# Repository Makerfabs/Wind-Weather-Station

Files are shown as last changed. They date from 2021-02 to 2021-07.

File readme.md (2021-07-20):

# Wind Weather Station

```c++
/*
Version:		V2.0
Author:			Vincent
Create Date:	2021/2/23
Note:
	2021/7/20: Add a weather station project.
	2021/5/5:Add Seeed UV Sensor example.
	
*/
```
[toc]

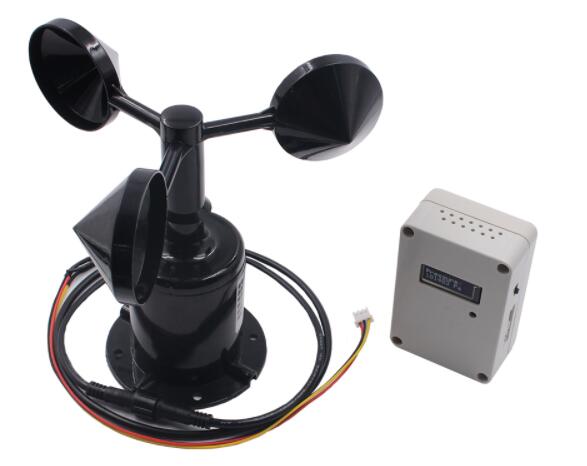
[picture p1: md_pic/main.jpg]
main


[DIY Wind Weather Station and Remote Monitor via MQTT](https://www.youtube.com/watch?v=OUKzvni5h78)

# Makerfabs

[Makerfabs home page](https://www.makerfabs.com/)

[Makerfabs Wiki](https://makerfabs.com/wiki/index.php?title=Main_Page)

# Wind Weather Station

## Intruduce

### Product Link: [Open Wind Station GPRS/ MQTT](https://www.makerfabs.com/open-wind-statation-gprs-mqtt.html)

### Wiki Link:[Wind_Weather_Station](https://www.makerfabs.com/wiki/index.php?title=Wind_Weather_Station)

Weather station based on Maduino A9G.With onboard DHT11 temperature and humidity sensor, BMP280 air pressure sensor and SSD1306LCD screen.It can be connected with anemometer and PM2.5 air quality sensor.

## Feature

- Micro controller ATSAMD21G18, 32-Bit ARM Cortex M0+
- PM2.5 monitoring with expanded PM2.5 sensor
- GPS for locating
- Grove connectors for customers’ expanded testing
- OLED display for real-time checking& debugging
- Onboard buzzer/ SD card slot
- High-power 1000 mAH battery for long-term usage
- Solar panel charging
- With Case(but not water-proof), could be re-made for water-proof with glues easily
- Arduino compatible/ Support MQTT

### Front:

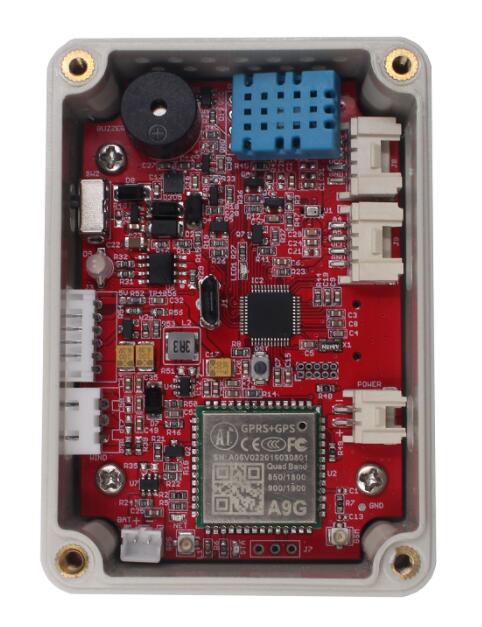
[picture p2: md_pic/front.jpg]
front


### Back:
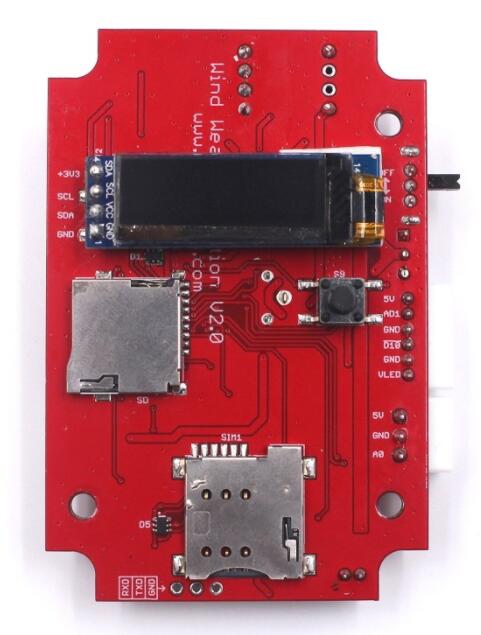
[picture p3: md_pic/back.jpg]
back


### Interface:

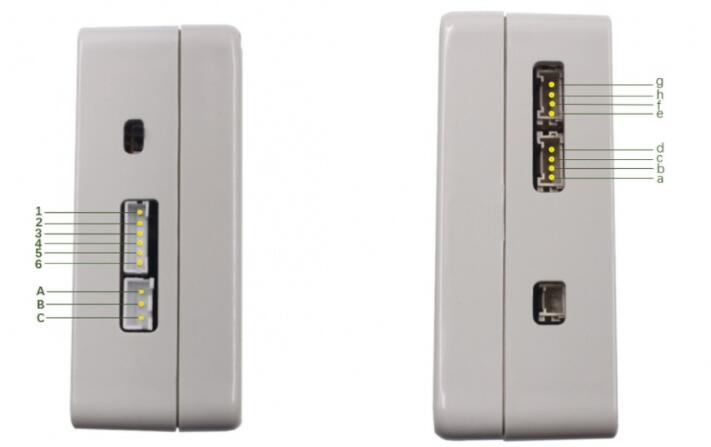
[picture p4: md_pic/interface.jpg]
interface


1. Interface of anemometer

| Pin | Mark | Definition |
| ---- | ---- | ---- |
| A | VCC | Power supply |
| B | GND | Grounding |
| C | A0 | Data input  |

2. Interface of CO2 sensor

| Pin| 	Mark	|Definition |
| ---- | ---- | ---- |
| 1 | 5V | Power supply |
| 2 | AD1 |  Data input |
| 3 | GND |  Grounding |
| 4 | D10 |  LED Driving |
| 5 | GND |  LED grounding |
| 6 | VLED | LED Power supply |

3. Other interfaces

| Pin| 	Mark	|Definition |
| ---- | ---- | ---- |
| a | | GND |
| b | | VCC |
| c | | A5 |
| d | | A4 |
| e | | GND |
| f | | VCC |
| g | | SDA |
| h | | SCL |

# Example

## Compiler Options

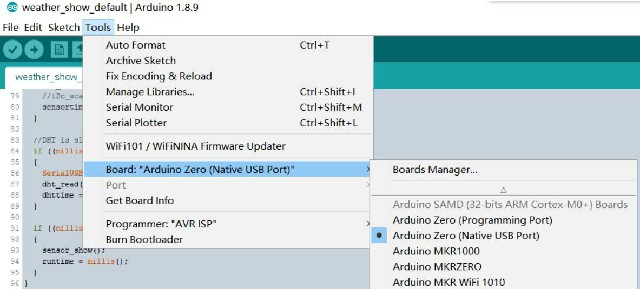
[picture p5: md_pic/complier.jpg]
complier


Choice Arduino Zero (Native USB Port).

## weather_show_default

Factory default program, collect temperature, humidity, air pressure, wind speed, PM2.5 index, the sensor data display on SSD1306.

- Connect anemometer or air quality sensor (or both) to weather station.
- Connect to battery or USB cable.
- LCD screen will show sensor value.

## at_demo

A simple AT directive demo is provided.

## weather_MQTT

A simple example of MQTT communication. Data is sent by MQTT protocol through A9G module. Need a SIM card that can be connected to the Internet.

## low_power

A simple low-power test program that turns off power to the A9G and all sensors and puts the SAMD21 to sleep.

# Project : Weather Station

**A long-maintained weather station project, real-time weather from Makerfabs can be accessed via ThingSpeak and Makerfabs Wiki (Shenzhen, China).**

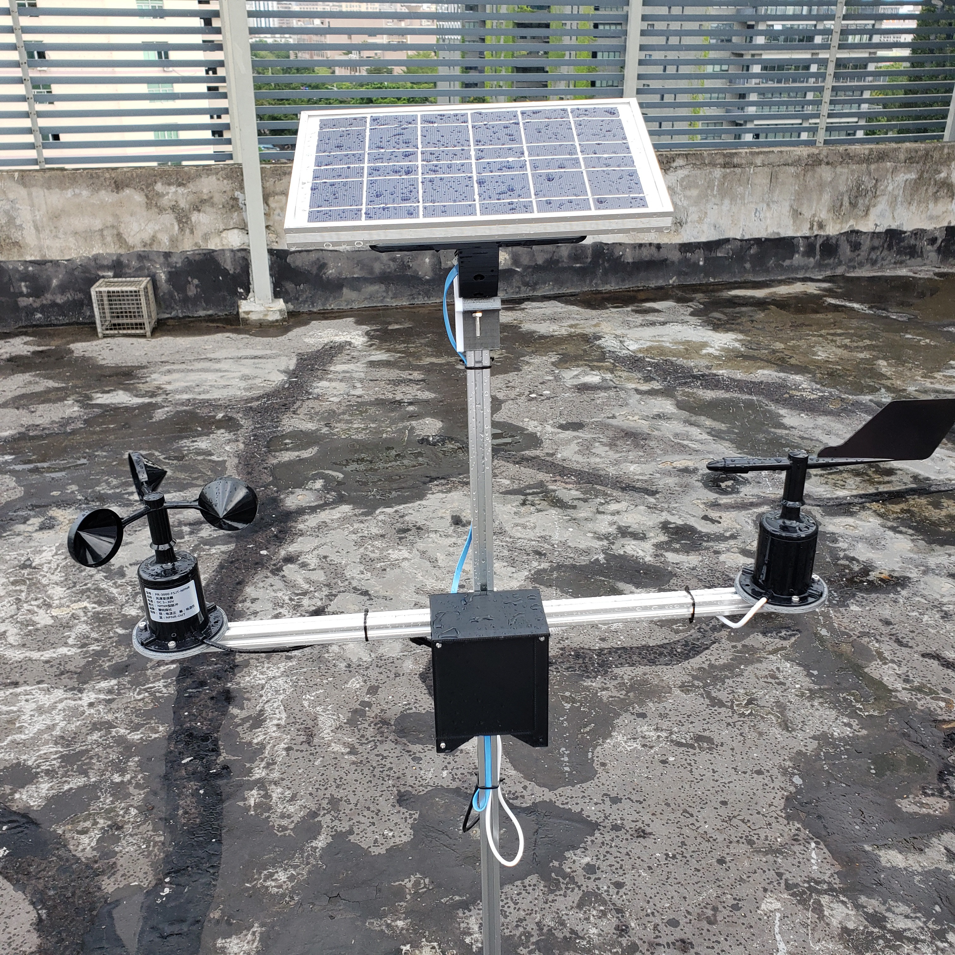
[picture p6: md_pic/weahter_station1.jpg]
weather_station


The weather link is as follows:

[Makerfabs Wiki Weather](https://www.makerfabs.com/wiki/index.php?title=Weather_Show)

[ThingSpeak Show](https://thingspeak.com/channels/1243124)

[HackDay.io wind weather station](https://hackaday.io/project/177972-wind-weather-station)

## Code

The code is divided into two parts, one is the Weather Station, which measures the weather data and sends it to ThingSpeak and MQTT servers.

And there is a use of ESP32 as a terminal to receive real-time information code.

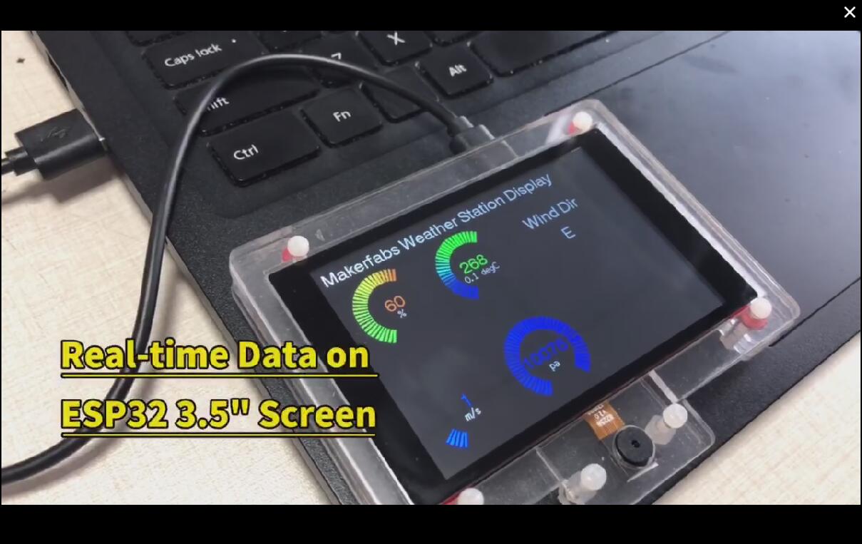
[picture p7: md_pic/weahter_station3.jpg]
weather_station3


## Weather Analysis

The test lasted for ten days in June, and the analysis data are as follows.

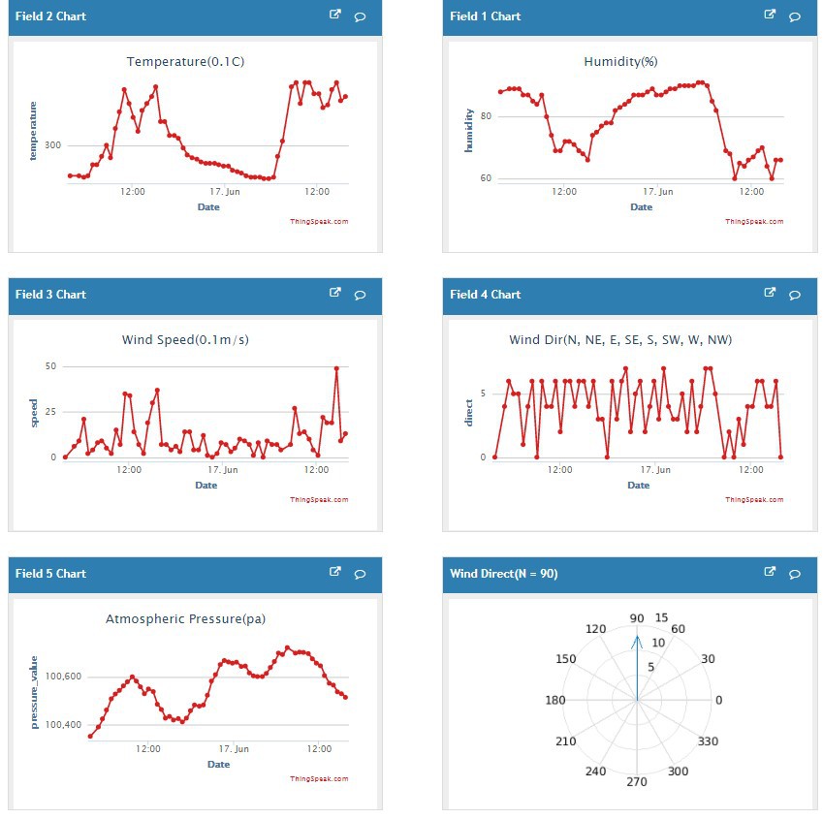
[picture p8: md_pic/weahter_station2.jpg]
weather_station


And I also make a python file to analyse data, like max or min temperature.

Code is in : \Wind-Weather-Station\Project_WeatherStation\csv_read\csv_test.py

## 3D file

Weather station box and anemometer, wind direction gauge, fixed structure of solar panel.

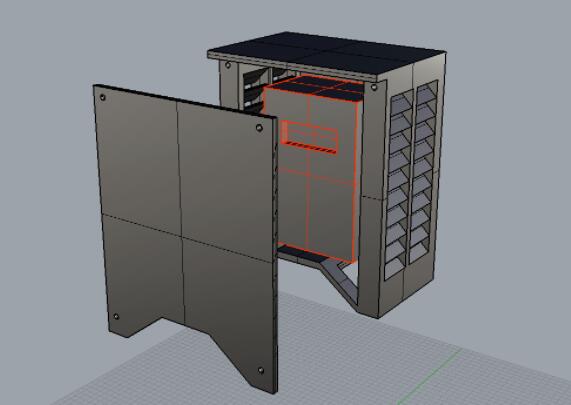
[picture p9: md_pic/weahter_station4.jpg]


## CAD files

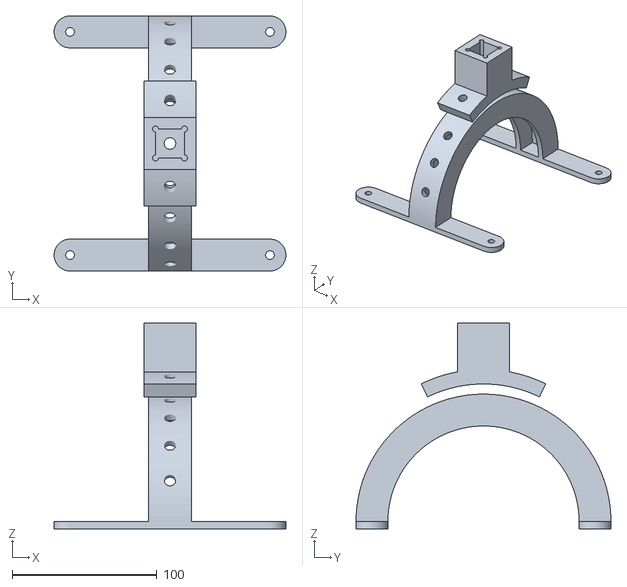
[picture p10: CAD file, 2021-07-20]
STL/weathersation_2.stl.stl
160.0 x 176.0 x 142.0

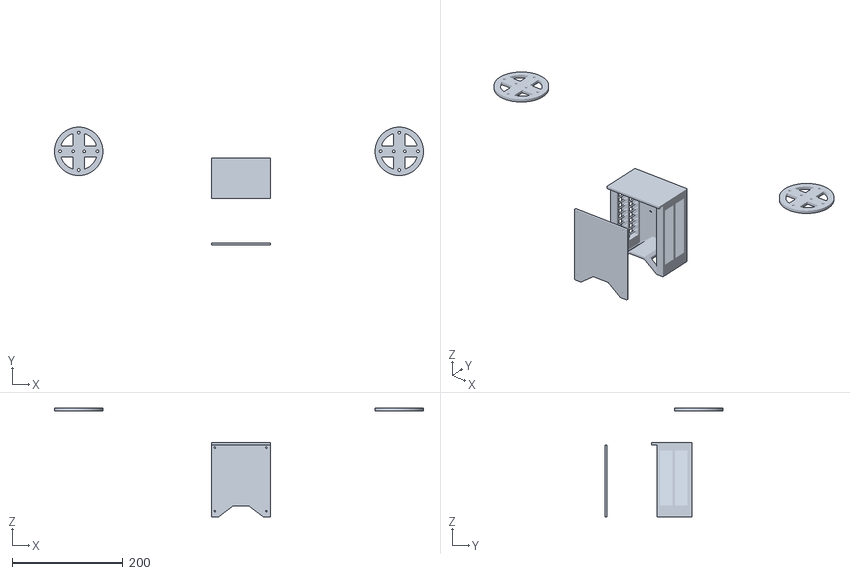
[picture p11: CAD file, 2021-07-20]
STL/weathersation_1.stl
666.5 x 212.8 x 196.0

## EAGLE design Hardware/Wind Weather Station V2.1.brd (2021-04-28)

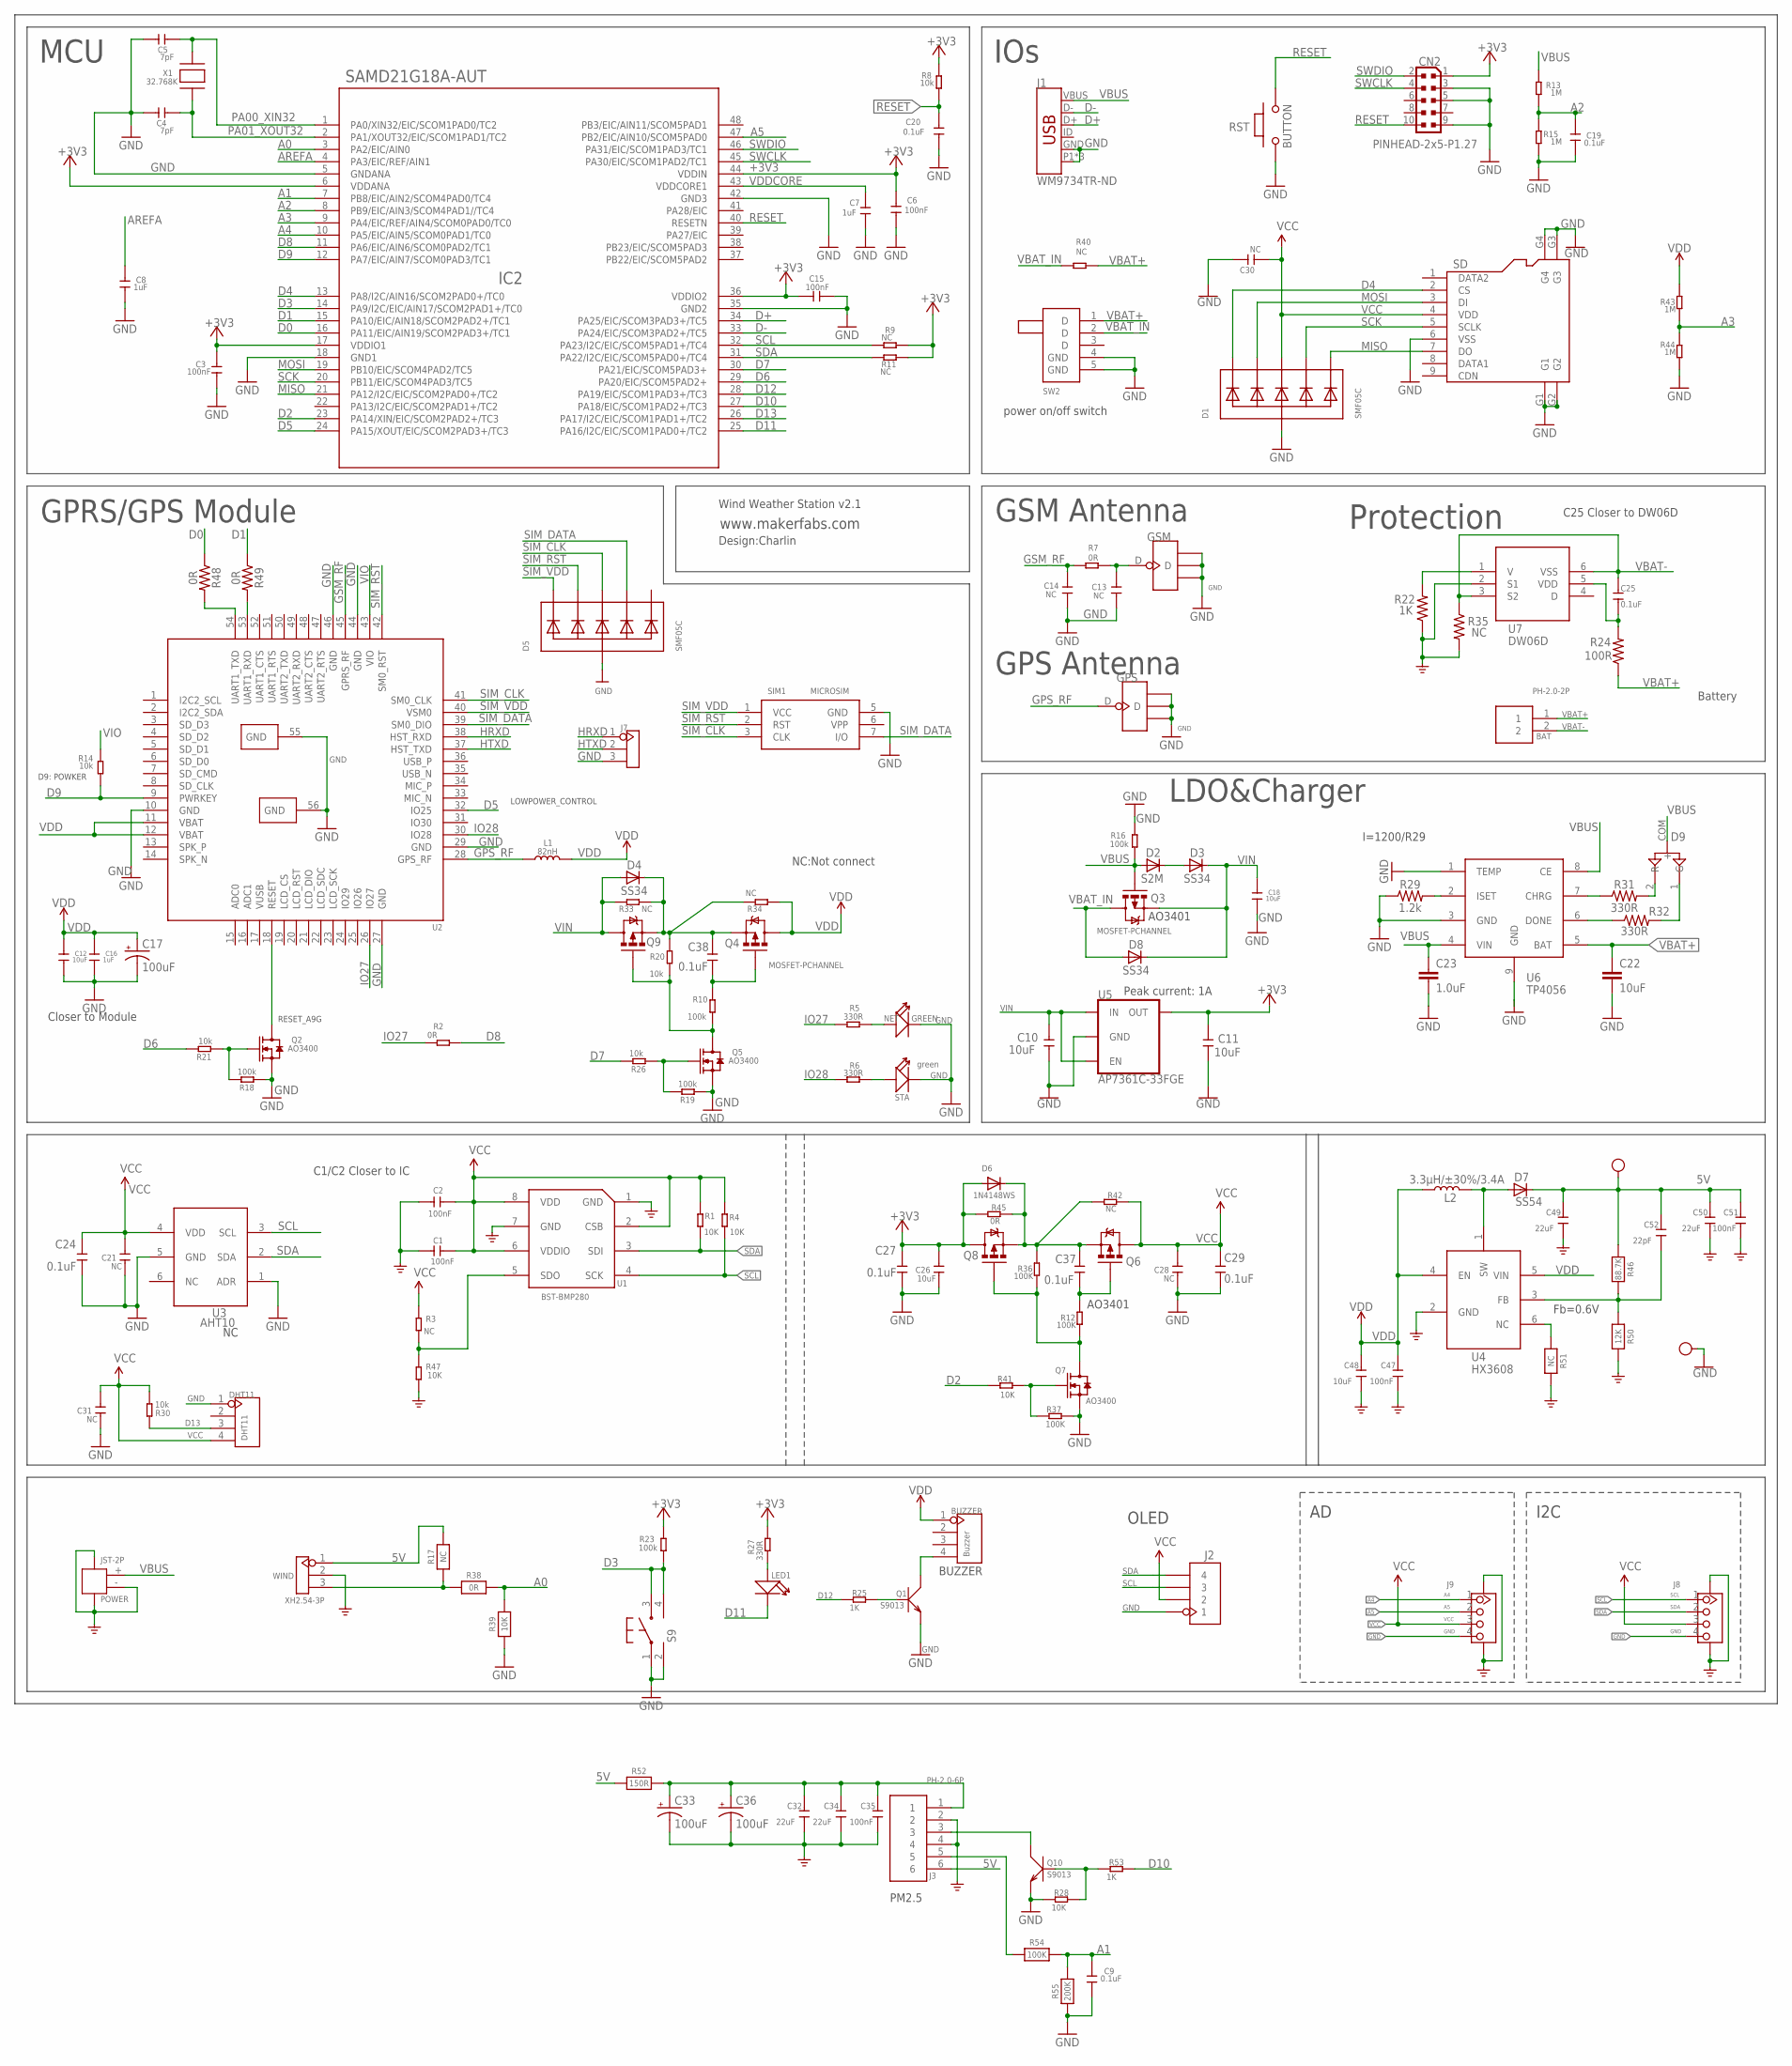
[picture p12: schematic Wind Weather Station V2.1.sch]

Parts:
5V: TEST-POINT'4545'; TP-D45MIL
BAT: PH-2.0-2P
BUZZER: Buzzer; 4P-65/35ROUND
C1, C2, C35, C47, C51: 100nF; C0603
C3, C6, C15: 100nF; 0603
C4, C5: 7pF; 0603
C7, C8, C16: 1uF; 0603
C9, C19, C20, C24, C25, C27, C29, C37, C38: 0.1uF; 0603
C10, C11, C12, C18, C26: 10uF; 0603
C13, C14: NC; 0402
C17, C33, C36: 100uF; EIA3528
C21, C28, C31: NC; 0603
C22: 10uF; 1206
C23: 1.0uF; 0603
C30: NC; DISCRETE_C0603
C32, C34, C49, C50: 22uF; C0603
C48: 10uF; C0603
C52: 22pF; C0603
CN2: PINHEAD-2x5-P1.27; PINHEAD_2X05_127
D1, D5: SMF05C; SOT363
D2: S2M; DO-214AC
D3, D4, D8: SS34; DO-214AC
D6: 1N4148WS; SOD-323F
D7: SS54; DO-214AC
D9: LED-ARG-3P'-3MM'; LED-3P-2.54-3MM
DHT11: DHT11; 4P-65/35ROUND
GND: TEST-POINT'4545'; TP-D45MIL
GPS: ANTENNA-U-FL; 4P-U-FL
GSM: ANTENNA-U-FL; 4P-U-FL
IC2: SAMD21G18A-AUT; TQFP48-7X7
J1: WM9734TR-ND; USB-B-MICRO-SMD_VERT
J2: HEADER-1X4P; SMD4-2.54P
J3: PH-2.0-6P
J7: HEADER-3P-2.54; 3P-2.54
J8, J9: GROVE-CONNECTOR-SMD'90D'; HW4-SMD-2.0-90D
L1: 82nH; L0603
L2: 3.3µH/±30%/3.4A; CR54
LED1: DISCRETE_LED0603; DISCRETE_LED-0603
NET: GREEN; DISCRETE_LED-0603
POWER: JST-2P; HW2-SMD-2.0-90D
Q1, Q10: S9013; SOT23
Q2, Q5: AO3400; SOT23@1
Q3, Q4, Q6, Q8, Q9: MOSFET-PCHANNEL; SOT23-3
Q7: AO3400; DISCRETE_SOT23
R1, R4, R28, R41, R47: 10K; R0603
R2, R7, R45: 0R; R0603
R3, R9, R11, R33, R34, R40, R42: NC; R0603
R5, R6, R27: 330R; R0603
R8, R14, R20, R21, R26, R30: 10k; R0603
R10, R16, R18, R19, R23: 100k; R0603
R12, R36, R37: 100K; R0603
R13, R15, R43, R44: 1M; R0603
R17, R51: NC; 0603-NO
R22: 1K; 0603
R24: 100R; 0603
R25, R53: 1K; R0603
R29: 1.2k; 0603
R31, R32: 330R; 0603
R35: NC; 0603
R38: 0R; 0603-NO
R39: 10K; 0603-NO
R46: 88.7K; 0603-NO
R48, R49: 0R; 0603
R50: 12K; 0603-NO
R52: 150R; 0603-NO
R54: 100K; 0603-NO
R55: 200K; 0603-NO
RST: BUTTON; 157SW
S9: SWITCHES; SMD4-6*6
SD: HOLDER-MICROSD-9P; 9P-SMD-W/-RING
SIM1: MICROSIM
STA: green; LED-0603
SW2: SWITCH; DIP5-8.6*4.5MM
U1: BST-BMP280; LGA8-0.65-2X2.5X0.95MM
U2: A9G
U3: AHT10; SMD6-127P-400L500W
U4: HX3608; SOT-23-6
U5: AP7361C-33FGE; 8-UDFN
U6: TP4056; SOP8-1.27P
U7: DW06D; SOT-23-6
WIND: XH2.54-3P
X1: 32.768K; XTAL3215

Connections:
5V: 5V.T, C49.1, C50.1, C51.1, C52.1, D7.C, J3.6, R17.2, R46.1, R52.1, WIND.1
+3V3: C3.2, C6.1, C11.2, C15.1, C26.2, C27.2, CN2.1, D6.A, IC2.6 (VDDANA), IC2.17 (VDDIO1), IC2.36 (VDDIO2), IC2.44 (VDDIN), Q8.3 (D), R8.2, R9.2, R11.2, R23.2, R27.2, R45.2, U5.1 (OUT)
A0: IC2.3 (PA2/EIC/AIN0), R38.2, R39.2
A1: C9.1, IC2.7 (PB8/EIC/AIN2/SCOM4PAD0/TC4), R54.2, R55.2
A2: C19.1, IC2.8 (PB9/EIC/AIN3/SCOM4PAD1//TC4), R13.1, R15.2
A3: IC2.9 (PA4/EIC/REF/AIN4/SCOM0PAD0/TC0), R43.1, R44.2
A4: IC2.10 (PA5/EIC/AIN5/SCOM0PAD1/TC0), J9.1
A5: IC2.47 (PB2/EIC/AIN10/SCOM5PAD0), J9.2
AREFA: C8.1, IC2.4 (PA3/EIC/REF/AIN1)
D0: IC2.16 (PA11/EIC/AIN19/SCOM2PAD3+/TC1), R48.1
D1: IC2.15 (PA10/EIC/AIN18/SCOM2PAD2+/TC1), R49.1
D2: IC2.23 (PA14/XIN/EIC/SCOM2PAD2+/TC3), R41.2
D3: IC2.14 (PA9/I2C/EIC/AIN17/SCOM2PAD1+/TC0), R23.1, S9.3, S9.4
D4: D1.1 (C1), IC2.13 (PA8/I2C/AIN16/SCOM2PAD0+/TC0), SD.2 (CS)
D5: IC2.24 (PA15/XOUT/EIC/SCOM2PAD3+/TC3), U2.32 (IO25)
D6: IC2.29 (PA20/EIC/SCOM5PAD2+), R21.2
D7: IC2.30 (PA21/EIC/SCOM5PAD3+), R26.2
D8: IC2.11 (PA6/EIC/AIN6/SCOM0PAD2/TC1), R2.2
D9: IC2.12 (PA7/EIC/AIN7/SCOM0PAD3/TC1), R14.1, U2.9 (PWRKEY)
D10: IC2.27 (PA18/EIC/SCOM1PAD2+/TC3), R53.2
D11: IC2.25 (PA16/I2C/EIC/SCOM1PAD0+/TC2), LED1.-
D12: IC2.28 (PA19/EIC/SCOM1PAD3+/TC3), R25.1
D13: DHT11.3, IC2.26 (PA17/I2C/EIC/SCOM1PAD1+/TC2), R30.1
D+: IC2.34 (PA25/EIC/SCOM3PAD3+/TC5), J1.D+
D-: IC2.33 (PA24/EIC/SCOM3PAD2+/TC5), J1.D-
DONE: R32.1, U6.6 (DONE)
GND: C1.2, C2.2, C3.1, C4.2, C5.2, C6.2, C7.2, C8.2, C9.2, C10.1, C11.1, C12.1, C13.1, C14.1, C15.2, C16.1, C17.C (-), C18.1, C19.2, C20.1, C21.1, C22.2, C23.2, C24.1, C26.1, C27.1, C28.1, C29.1, C30.1, C31.1, C32.2, C33.C (-), C34.2, C35.2, C36.C (-), C47.2, C48.2, C49.2, C50.2, C51.2, CN2.3, CN2.5, CN2.9, D1.2 (A), D5.2 (A), DHT11.1, GND.T, GPS.GND1, GPS.GND2, GPS.GND3, GSM.GND1, GSM.GND2, GSM.GND3, IC2.5 (GNDANA), IC2.18 (GND1), IC2.35 (GND2), IC2.42 (GND3), J1.GND, J1.P1 (SHIELD), J1.P2 (SHIELD), J1.P3 (SHIELD), J2.1, J3.2, J3.4, J7.3, J8.4, J8.SS1, J8.SS2, J9.4, J9.SS1, J9.SS2, NET.-, POWER.3, POWER.4, POWER.- (2), Q1.2 (E), Q2.2 (S), Q5.2 (S), Q7.2 (S), Q10.2 (E), R15.1, R16.2, R18.1, R19.1, R22.1, R28.1, R29.1, R35.2, R37.1, R39.1, R44.1, R47.1, R50.2, R51.2, R55.1, RST.2, S9.1, S9.2, SD.6 (VSS), SD.G1, SD.G2, SD.G3, SD.G4, SIM1.5 (GND), STA.-, SW2.4 (GND), SW2.5 (GND), U1.1 (GND), U1.7 (GND), U2.10 (GND), U2.27 (GND), U2.29 (GND), U2.44 (GND), U2.46 (GND), U2.55 (GND), U2.56 (GND), U3.1 (ADR), U3.5 (GND), U4.2 (GND), U5.4 (GND), U5.EP (GND), U6.1 (TEMP), U6.3 (GND), U6.9 (GND), U7.2 (S1), WIND.2
GPS_RF: GPS.D, L1.1, U2.28 (GPS_RF)
GSM_RF: C14.2, R7.1, U2.45 (GPRS_RF)
HRXD: J7.1, U2.38 (HST_RXD)
HTXD: J7.2, U2.37 (HST_TXD)
IO27: R2.1, R5.1, U2.26 (IO27)
IO28: R6.1, U2.30 (IO28)
ISET: R29.2, U6.2 (ISET)
MISO: D1.6 (C5), IC2.21 (PA12/I2C/EIC/SCOM2PAD0+/TC2), SD.7 (DO)
MOSI: D1.3 (C2), IC2.19 (PB10/EIC/SCOM4PAD2/TC5), SD.3 (DI)
unnamed: R6.2, STA.+
unnamed: D2.C, D3.A
unnamed: C38.1, Q4.1 (G), R10.2
unnamed: Q5.1 (G), R19.2, R26.1
unnamed: LED1.+, R27.1
unnamed: C37.2, D6.C, Q6.2 (S), Q8.2 (S), R36.2, R42.2, R45.1
unnamed: NET.+, R5.2
unnamed: Q2.3 (D), U2.18 (RESET)
unnamed: BUZZER.4, Q1.3 (C)
unnamed: R17.1, R38.1, WIND.3
unnamed: C38.2, D4.C, Q4.2 (S), Q9.2 (S), R20.2, R33.1, R34.2
unnamed: Q2.1 (G), R18.2, R21.1
unnamed: D9.1 (G), R32.2
unnamed: R31.1, U6.7 (CHRG)
unnamed: Q7.3 (D), Q8.1 (G), R12.1, R36.1
unnamed: C25.2, R24.2, U7.5 (VDD)
unnamed: R22.2, U7.1 (V)
unnamed: D9.2 (R), R31.2
unnamed: Q7.1 (G), R37.2, R41.1
unnamed: R3.1, R47.2, U1.5 (SDO)
unnamed: R49.2, U2.53 (UART1_RXD)
unnamed: R48.2, U2.54 (UART1_TXD)
unnamed: D7.A, L2.P$2 (2), U4.1 (SW)
unnamed: Q1.1 (B), R25.2
unnamed: C52.2, R46.2, R50.1, U4.3 (FB)
unnamed: R51.1, U4.6 (NC)
unnamed: C32.1, C33.A (+), C34.1, C35.1, C36.A (+), J3.1, R52.2
unnamed: Q10.1 (B), R28.2, R53.1
unnamed: J3.3, Q10.3 (C)
unnamed: J3.5, R54.1
unnamed: Q5.3 (D), Q9.1 (G), R10.1, R20.1
unnamed: C37.1, Q6.1 (G), R12.2
unnamed: C13.2, GSM.D, R7.2
PA00_XIN32: C5.1, IC2.1 (PA0/XIN32/EIC/SCOM1PAD0/TC2), X1.P$2
PA01_XOUT32: C4.1, IC2.2 (PA1/XOUT32/EIC/SCOM1PAD1/TC2), X1.P$1
RESET: C20.2, CN2.10, IC2.40 (RESETN), R8.1, RST.1
SCK: D1.5 (C4), IC2.20 (PB11/EIC/SCOM4PAD3/TC5), SD.5 (SCLK)
SCL: IC2.32 (PA23/I2C/EIC/SCOM5PAD1+/TC4), J2.3, J8.1, R4.1, R9.1, U1.4 (SCK), U3.3 (SCL)
SDA: IC2.31 (PA22/I2C/EIC/SCOM5PAD0+/TC4), J2.4, J8.2, R1.1, R11.1, U1.3 (SDI), U3.2 (SDA)
SIM_CLK: D5.4 (C3), SIM1.3 (CLK), U2.41 (SM0_CLK)
SIM_DATA: D5.5 (C4), SIM1.7 (I/O), U2.39 (SM0_DIO)
SIM_RST: D5.3 (C2), SIM1.2 (RST), U2.42 (SM0_RST)
SIM_VDD: D5.1 (C1), SIM1.1 (VCC), U2.40 (VSM0)
SWCLK: CN2.4, IC2.45 (PA30/EIC/SCOM1PAD2/TC1)
SWDIO: CN2.2, IC2.46 (PA31/EIC/SCOM1PAD3/TC1)
VBAT+: BAT.1, C22.1, R24.1, R40.2, SW2.1 (D), U6.5 (BAT)
VBAT-: BAT.2, C25.1, R35.1, U7.3 (S2), U7.6 (VSS)
VBAT_IN: D8.A, Q3.3 (D), R40.1, SW2.2 (D)
VBUS: C23.1, D2.A, D9.COM (+), J1.VBUS, POWER.+ (1), Q3.1 (G), R13.2, R16.1, U6.4 (VIN), U6.8 (CE)
VCC: C1.1, C2.1, C21.2, C24.2, C28.2, C29.2, C30.2, C31.2, D1.4 (C3), DHT11.4, J2.2, J8.3, J9.3, Q6.3 (D), R1.2, R3.2, R4.2, R30.2, R42.1, SD.4 (VDD), U1.2 (CSB), U1.6 (VDDIO), U1.8 (VDD), U3.4 (VDD)
VDD: BUZZER.1, C12.2, C16.2, C17.A (+), C47.1, C48.1, L1.2, L2.P$1 (1), Q4.3 (D), R34.1, R43.2, U2.11 (VBAT), U2.12 (VBAT), U4.4 (EN), U4.5 (VIN)
VDDCORE: C7.1, IC2.43 (VDDCORE1)
VIN: C10.2, C18.2, D3.C, D4.A, D8.C, Q3.2 (S), Q9.3 (D), R33.2, U5.5 (EN), U5.8 (IN)
VIO: R14.2, U2.43 (VIO)

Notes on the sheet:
BUZZER
GSM Antenna
GPRS/GPS Module
LOWPOWER_CONTROL
RESET_A9G
D9: POWKER
Peak current: 1A
www.makerfabs.com
MCU
IOs
LDO&Charger
GPS Antenna
Design:Charlin
Closer to Module
AO3401
I=1200/R29
Wind Weather Station v2.1
NC:Not connect
Battery
C25 Closer to DW06D
Protection
I2C
C1/C2 Closer to IC
power on/off switch
OLED
Fb=0.6V
PM2.5

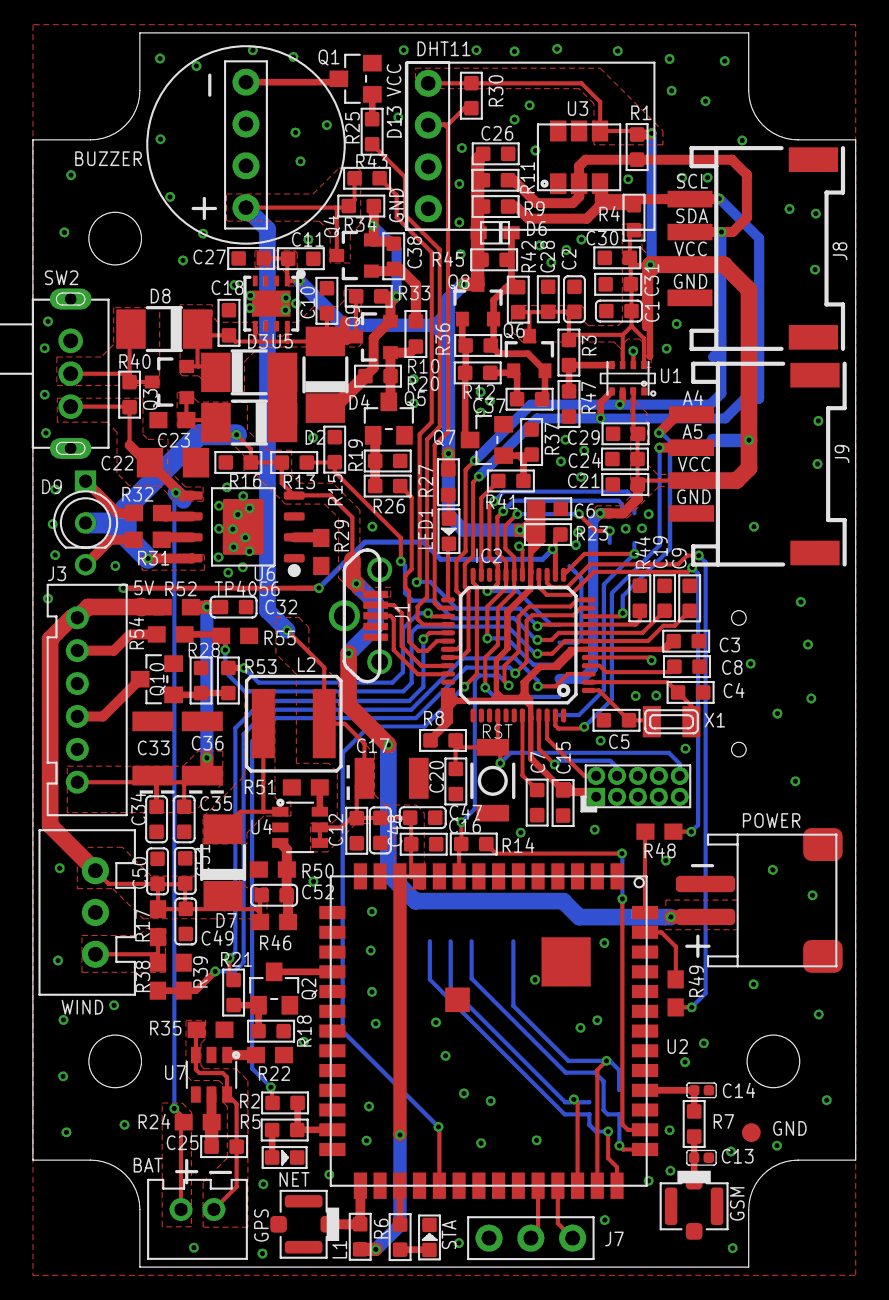
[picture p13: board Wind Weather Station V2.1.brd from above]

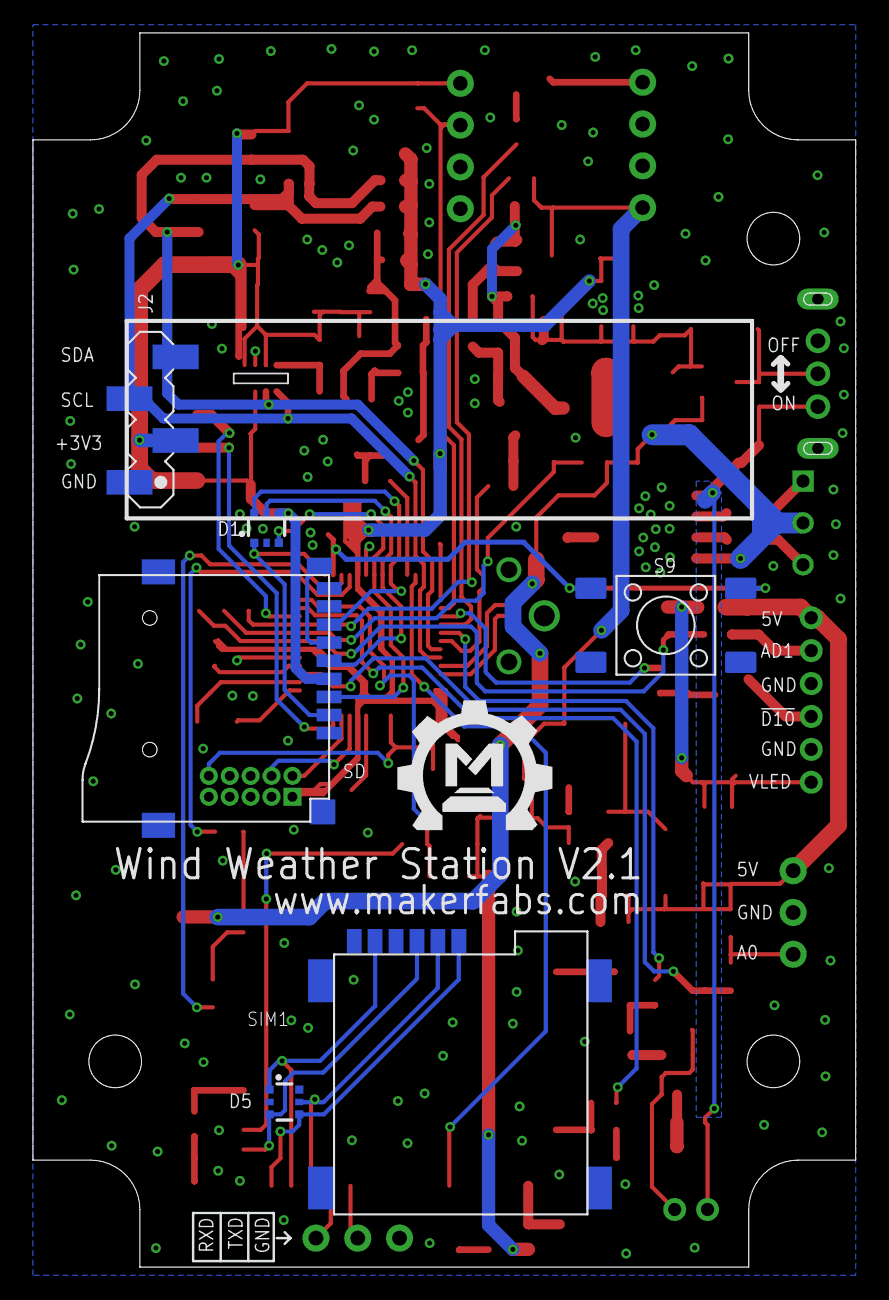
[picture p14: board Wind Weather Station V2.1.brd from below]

Board: 2 copper layers, 50.0 x 75.0 mm, 154 parts (7 on the bottom side), 90 nets.

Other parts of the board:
U$2: MAKERFABS-0.3

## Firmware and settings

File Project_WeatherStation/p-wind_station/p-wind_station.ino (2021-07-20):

#include <Wire.h>
#include <Adafruit_BMP280.h>
#include <Adafruit_GFX.h>
#include <Adafruit_SSD1306.h>
#include <DHT.h>

#include "sensor.h"
#include "ArduinoLowPower.h"

#define DEBUG true
#define VCC_PIN 2 //3.3V
#define VDD_PIN 7 //5V
#define PWR_KEY 9 //A9G
#define BUZZER_PIN 12

#define pinInterrupt A0 // the number of the Wind Speed sensor pin

#define buttonPin 3 // the number of the pushbutton pin

#define SCREEN_WIDTH 128 // OLED display width, in pixels
#define SCREEN_HEIGHT 32 // OLED display height, in pixels

#define OLED_RESET -1 // Reset pin # (or -1 if sharing Arduino reset pin)
Adafruit_SSD1306 display(SCREEN_WIDTH, SCREEN_HEIGHT, &Wire, OLED_RESET);

Sensor_value s_v = {0, 0, 0, 0, 0};

int Count = 0;
int runtime = 0;
int before_sleep = 0;
int sensortime = 0;
int show_index = 0;
int reset_count = 0;

int pm25_value = 0;

bool ModuleState = false;

unsigned long lastDebounceTime = 0; // the last time the output pin was toggled
unsigned long debounceDelay = 1000; // the debounce time; increase if the output flickers

void setup()
{
    SerialUSB.begin(115200);
    SerialUSB.println("---------------Start----------------------");

    Serial1.begin(115200);

    pin_init();
    SerialUSB.println("Pin init over");

    delay(10000);

    // //PM2.5
    // for (int i = 0; i < 10; i++)
    // {
    //     pm25_value = pm25();
    //     delay(3000);
    // }

    // SSD1306_SWITCHCAPVCC = generate display voltage from 3.3V internally
    if (!display.begin(SSD1306_SWITCHCAPVCC, 0x3C))
    { // Address 0x3C for 128x32
        Serial.println(F("SSD1306 allocation failed"));
        for (;;)
            ; // Don't proceed, loop forever
    }
    SerialUSB.println("SSD1306 found");

    sensor_init();

    logo_show();

    wind_count_start();
    get_weather();
    wind_count_end();

    while (0)
        ;

    at_commands_init();
    at_commands_send();
    before_sleep = millis();
}

// typedef struct
// {
//     int humidity;
//     int temperature;
//     int speed;
//     int direct;
//     int pressure_value;
// } Sensor_value;

void loop()
{
    SerialUSB.println("loop");
    while (Serial1.available() > 0)
    {
        SerialUSB.write(Serial1.read());
        yield();
    }
    delay(3000);
    if (millis() - before_sleep >= 1000L)
    { // Execute every TBD ms
        before_sleep = millis();
        SerialUSB.println("Prepare to sleep");
        pin_closeall();
        LowPower.attachInterruptWakeup(RTC_ALARM_WAKEUP, dummy, CHANGE);
        LowPower.sleep(60000);
    }
}
void pin_init()
{
    pinMode(VDD_PIN, OUTPUT);
    pinMode(VCC_PIN, OUTPUT);
    pinMode(PWR_KEY, OUTPUT);
    pinMode(BUZZER_PIN, OUTPUT);
    pinMode(PM_LED_PIN, OUTPUT);

    pinMode(pinInterrupt, INPUT_PULLUP); //set as input pin

    digitalWrite(VDD_PIN, LOW);
    delay(500);
    digitalWrite(VDD_PIN, HIGH);

    digitalWrite(VCC_PIN, LOW);
    delay(500);
    digitalWrite(VCC_PIN, HIGH);

    //restart a9g
    digitalWrite(PWR_KEY, LOW);
    delay(3000);
    digitalWrite(PWR_KEY, HIGH);

    digitalWrite(BUZZER_PIN, HIGH);
    delay(500);
    digitalWrite(BUZZER_PIN, LOW);

    delay(1000);
}

void pin_closeall()
{
    digitalWrite(VDD_PIN, LOW);
    digitalWrite(VCC_PIN, LOW);
    digitalWrite(PWR_KEY, LOW);

    digitalWrite(BUZZER_PIN, HIGH);
    delay(500);
    digitalWrite(BUZZER_PIN, LOW);

    SerialUSB.println("Close all power");

    delay(1000);
}

void wind_count_start()
{
    attachInterrupt(digitalPinToInterrupt(pinInterrupt), onChange, FALLING);
}

void wind_count_end()
{
    detachInterrupt(digitalPinToInterrupt(pinInterrupt));
}

void logo_show()
{
    display.clearDisplay();

    display.setTextColor(SSD1306_WHITE);
    display.setTextSize(2); // Draw 2X-scale text
    display.setCursor(10, 0);
    display.println(F("Makerfabs"));
    display.setTextSize(1);
    display.setCursor(10, 16);
    display.println(F("Weather Station"));
    display.display(); // Show initial text
    delay(100);
}

void sensor_show()
{
    display.clearDisplay();
    display.setTextColor(SSD1306_WHITE);
    display.setTextSize(2);

    switch (show_index)
    {
    case 0:

        display.setCursor(0, 0);
        display.print("Temp:");
        display.print(s_v.temperature / 10.0);
        display.println(" C");

        display.setCursor(0, 16);
        display.print("Humi:");
        display.print(s_v.humidity);
        display.println(" %");
        break;

    case 1:
        display.setCursor(0, 0);
        display.print("Dir:");
        display.print(s_v.direct);
        display.println("");

        display.setCursor(0, 16);
        display.print("Speed:");
        display.print(s_v.speed / 10.0);
        display.println(" m/s");
        break;

    case 2:
        display.setCursor(0, 0);
        display.println("Pressure:");

        display.setCursor(0, 16);
        display.print(s_v.pressure_value);
        display.println(" Pa");
        break;
    }

    display.display(); // Show initial text
    show_index++;
    show_index %= 3;
}

void onChange()
{
    if (digitalRead(pinInterrupt) == LOW)
    {
        SerialUSB.println("onChange");
        Count++;
    }
}

void wind_speed()
{
    if ((millis() - lastDebounceTime) > debounceDelay)
    {
        lastDebounceTime = millis();
        //0.1m/s
        s_v.speed = (int)(Count * 8.75 * 0.01 * 10);
        // SerialUSB.print(s_v.speed);
        Count = 0;
        // SerialUSB.println("m/s");
    }
}

//cost at least 30 seconds
void get_weather()
{
    long get_weather_time = millis();
    while (1)
    {
        if ((millis() - get_weather_time) > 30000)
        {
            SerialUSB.println("Already get weather");
            return;
        }

        wind_speed();

        if ((millis() - sensortime) > 4000)
        {
            SerialUSB.println("Read sensor");
            sensor_read(&s_v);
            sensortime = millis();
        }

        if ((millis() - runtime) > 2000)
        {
            sensor_show();
            runtime = millis();
        }
    }
}

void at_commands_init()
{
    SerialUSB.println("Start send at init");
    while (Serial1.available() > 0)
    {
        SerialUSB.write(Serial1.read());
        yield();
    }
    sendData("AT", 3000, DEBUG);
    sendData("AT+CCID", 3000, DEBUG);
    sendData("AT+CREG?", 3000, DEBUG);
    sendData("AT+CGATT=1", 3000, DEBUG);

    sendData("AT+CGDCONT=1,\"IP\",\"CMNET\"", 3000, DEBUG);
    sendData("AT+CGACT=1,1", 3000, DEBUG);
    sendData("AT+MQTTCONN=\"test.mosquitto.org\",1883,\"mqttx_0931852d35\",120,0", 3000, DEBUG);

    /* For test
    sendData("AT+HTTPGET=\"https://api.thingspeak.com/update?api_key=5F9US450RPYGDBWZ&field1=1&field2=2&field3=3&field4=4&field5=5\"", 3000, DEBUG);
    sendData("AT+MQTTCONN=\"test.mosquitto.org\",1883,\"mqttx_0931852d35\",120,0", 3000, DEBUG);
    String topic_T = "AT+MQTTPUB=\"/public/TEST/makerfabs-T\",\"" + (String)1234567890 + "\",0,0,0";
    sendData(topic_T, 3000, DEBUG);
    */

    SerialUSB.println("At init over");
}

void at_commands_send()
{
    SerialUSB.println("Start send at-command");
    // h t s d p

    String mqtt_str = (String) "h" + s_v.humidity + "t" + s_v.temperature +
                      "s" + s_v.speed + "d" + s_v.direct + "p" + s_v.pressure_value + "q" + s_v.pm25;
    String topic_T = "AT+MQTTPUB=\"/public/TEST/makerfabs-T\",\"" + mqtt_str + "\",0,0,0";
    sendData(topic_T, 10000, DEBUG);

    String temperature_str = (String) "" + s_v.temperature / 10 + "." + s_v.temperature % 10;
    String windspeed_str = (String) "" + s_v.speed / 10 + "." + s_v.speed % 10;

    //NO WIND DIR
    s_v.direct = 0;

    String thing_speak_str = (String) "&field1=" + s_v.humidity + "&field2=" + temperature_str +
                             "&field3=" + windspeed_str + "&field4=" + s_v.direct +
                             "&field5=" + s_v.pressure_value + "&field6=" + s_v.pm25;
    //sendData("AT+HTTPGET=\"https://api.thingspeak.com/update?api_key=5F9US450RPYGDBWZ&field1=1&field2=2&field3=3&field4=4&field5=5\"", 3000, DEBUG);
    sendData("AT+HTTPGET=\"https://api.thingspeak.com/update?api_key=5F9US450RPYGDBWZ" + thing_speak_str + "\"", 10000, DEBUG);

    SerialUSB.println("End send at-command");
}

bool moduleStateCheck()
{
    int i = 0;
    bool moduleState = false;
    for (i = 0; i < 5; i++)
    {
        String msg = String("");
        msg = sendData("AT", 1000, DEBUG);
        if (msg.indexOf("OK") >= 0)
        {
            SerialUSB.println("A9/A9G Module had turned on.");
            moduleState = true;
            return moduleState;
        }
        delay(1000);
    }
    return moduleState;
}

String sendData(String command, const int timeout, boolean debug)
{
    String response = "";
    Serial1.println(command);
    long int time = millis();
    while ((time + timeout) > millis())
    {
        while (Serial1.available())
        {
            char c = Serial1.read();
            response += c;
        }
    }
    if (debug)
    {
        SerialUSB.print(response);
    }
    return response;
}

void dummy()
{
    // This function will be called once on device wakeup
    // You can do some little operations here (like changing variables which will be used in the loop)
    // Remember to avoid calling delay() and long running functions since this functions executes in interrupt context
    reset_count++;
    if (reset_count > 30)
        NVIC_SystemReset();
}

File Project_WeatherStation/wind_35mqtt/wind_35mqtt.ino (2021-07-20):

#include <WiFi.h>
#include <PubSubClient.h>
#include "alert.h"    // Out of range alert icon
#include <TFT_eSPI.h> // Hardware-specific library
#include <SPI.h>

// Meter colour schemes
#define RED2RED 0
#define GREEN2GREEN 1
#define BLUE2BLUE 2
#define BLUE2RED 3
#define GREEN2RED 4
#define RED2GREEN 5

#define TFT_GREY 0x2104 // Dark grey 16 bit colour

typedef struct
{
  int humidity;
  int temperature;
  int speed;
  int direct;
  int pressure_value;
} Sensor_value;

Sensor_value s_v = {0, 0, 0, 0, 0};
String dir_str[8] = {"N", "NE", "E", "SE", "S", "SW", "W", "NW"};

//WIFI
const char *ssid = "Makerfabs";
const char *password = "20160704";
const char *mqtt_server = "test.mosquitto.org"; //你的服务器地址

TFT_eSPI tft = TFT_eSPI(); // Invoke custom library with default width and height
WiFiClient espClient;
PubSubClient client(espClient);

uint32_t runTime = -99999; // time for next update
int value = 0;
int d = 0; // Variable used for the sinewave test waveform
boolean range_error = 0;

String msg = "h0t0s0d0p0";

void setup(void)
{
  Serial.begin(115200);

  tft.begin();
  tft.setRotation(1);
  tft.fillScreen(TFT_BLACK);

  tft.setTextColor(TFT_WHITE, TFT_BLACK);
  tft.drawString("Makerfabs Weather Station Display", 10, 10, 4);
  //tft.drawString("Wind Speed", 350, 10, 2);

  setup_wifi();
  client.setServer(mqtt_server, 1883); //MQTT默认端口是1883
  client.setCallback(callback);
}

void loop()
{
  mqtt_loop();
  if (millis() - runTime >= 5000L)
  { // Execute every TBD ms
    runTime = millis();

    // Set the the position, gap between meters, and inner radius of the meters
    int xpos = 20, ypos = 40, gap = 20, radius = 56;

    xpos = gap + ringMeter(s_v.humidity, 0, 100, xpos, ypos, radius, "%", GREEN2RED);           // Draw analogue meter
    xpos = gap + ringMeter(s_v.temperature, -100, 500, xpos, ypos, radius, "0.1 degC", BLUE2RED); // Draw analogue meter

    xpos = 20, ypos = 200;

    xpos = gap + ringMeter(s_v.speed, 0, 10, xpos, ypos, radius, "m/s", BLUE2BLUE);               // Draw analogue meter
    xpos = gap + ringMeter(s_v.pressure_value, 8000, 12000, xpos, ypos, radius, "pa", BLUE2BLUE); // Draw analogue meter

    tft.setTextColor(TFT_WHITE, TFT_BLACK);
    tft.drawString("Wind Dir", 360, 80, 4);
    tft.drawString(dir_str[s_v.direct], 360, 120, 4);
  }
}

// #########################################################################
//  Draw the meter on the screen, returns x coord of righthand side
// #########################################################################
int ringMeter(int value, int vmin, int vmax, int x, int y, int r, const char *units, byte scheme)
{
  // Minimum value of r is about 52 before value text intrudes on ring
  // drawing the text first is an option

  x += r;
  y += r; // Calculate coords of centre of ring

  int w = r / 3; // Width of outer ring is 1/4 of radius

  int angle = 150; // Half the sweep angle of meter (300 degrees)

  int v = map(value, vmin, vmax, -angle, angle); // Map the value to an angle v

  byte seg = 3; // Segments are 3 degrees wide = 100 segments for 300 degrees
  byte inc = 6; // Draw segments every 3 degrees, increase to 6 for segmented ring

  // Variable to save "value" text colour from scheme and set default
  int colour = TFT_BLUE;

  // Draw colour blocks every inc degrees
  for (int i = -angle + inc / 2; i < angle - inc / 2; i += inc)
  {
    // Calculate pair of coordinates for segment start
    float sx = cos((i - 90) * 0.0174532925);
    float sy = sin((i - 90) * 0.0174532925);
    uint16_t x0 = sx * (r - w) + x;
    uint16_t y0 = sy * (r - w) + y;
    uint16_t x1 = sx * r + x;
    uint16_t y1 = sy * r + y;

    // Calculate pair of coordinates for segment end
    float sx2 = cos((i + seg - 90) * 0.0174532925);
    float sy2 = sin((i + seg - 90) * 0.0174532925);
    int x2 = sx2 * (r - w) + x;
    int y2 = sy2 * (r - w) + y;
    int x3 = sx2 * r + x;
    int y3 = sy2 * r + y;

    if (i < v)
    { // Fill in coloured segments with 2 triangles
      switch (scheme)
      {
      case 0:
        colour = TFT_RED;
        break; // Fixed colour
      case 1:
        colour = TFT_GREEN;
        break; // Fixed colour
      case 2:
        colour = TFT_BLUE;
        break; // Fixed colour
      case 3:
        colour = rainbow(map(i, -angle, angle, 0, 127));
        break; // Full spectrum blue to red
      case 4:
        colour = rainbow(map(i, -angle, angle, 70, 127));
        break; // Green to red (high temperature etc)
      case 5:
        colour = rainbow(map(i, -angle, angle, 127, 63));
        break; // Red to green (low battery etc)
      default:
        colour = TFT_BLUE;
        break; // Fixed colour
      }
      tft.fillTriangle(x0, y0, x1, y1, x2, y2, colour);
      tft.fillTriangle(x1, y1, x2, y2, x3, y3, colour);
      //text_colour = colour; // Save the last colour drawn
    }
    else // Fill in blank segments
    {
      tft.fillTriangle(x0, y0, x1, y1, x2, y2, TFT_GREY);
      tft.fillTriangle(x1, y1, x2, y2, x3, y3, TFT_GREY);
    }
  }
  // Convert value to a string
  char buf[10];
  byte len = 3;
  if (value > 999)
    len = 5;
  dtostrf(value, len, 0, buf);
  buf[len] = ' ';
  buf[len + 1] = 0; // Add blanking space and terminator, helps to centre text too!
  // Set the text colour to default
  tft.setTextSize(1);

  if (value < vmin || value > vmax)
  {
    drawAlert(x, y + 90, 50, 1);
  }
  else
  {
    drawAlert(x, y + 90, 50, 0);
  }

  tft.setTextColor(TFT_WHITE, TFT_BLACK);
  // Uncomment next line to set the text colour to the last segment value!
  tft.setTextColor(colour, TFT_BLACK);
  tft.setTextDatum(MC_DATUM);
  // Print value, if the meter is large then use big font 8, othewise use 4
  if (r > 84)
  {
    tft.setTextPadding(55 * 3);   // Allow for 3 digits each 55 pixels wide
    tft.drawString(buf, x, y, 8); // Value in middle
  }
  else
  {
    tft.setTextPadding(3 * 14);   // Allow for 3 digits each 14 pixels wide
    tft.drawString(buf, x, y, 4); // Value in middle
  }
  tft.setTextSize(1);
  tft.setTextPadding(0);
  // Print units, if the meter is large then use big font 4, othewise use 2
  tft.setTextColor(TFT_WHITE, TFT_BLACK);
  if (r > 84)
    tft.drawString(units, x, y + 60, 4); // Units display
  else
    tft.drawString(units, x, y + 15, 2); // Units display

  // Calculate and return right hand side x coordinate
  return x + r;
}

void drawAlert(int x, int y, int side, boolean draw)
{
  if (draw && !range_error)
  {
    drawIcon(alert, x - alertWidth / 2, y - alertHeight / 2, alertWidth, alertHeight);
    range_error = 1;
  }
  else if (!draw)
  {
    tft.fillRect(x - alertWidth / 2, y - alertHeight / 2, alertWidth, alertHeight, TFT_BLACK);
    range_error = 0;
  }
}
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

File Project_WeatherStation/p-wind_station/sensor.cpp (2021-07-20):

#include "sensor.h"

DHT dht(DHTPIN, DHTTYPE);
Adafruit_BMP280 bmp;

void sensor_init()
{
    if (!bmp.begin(BMP280_I2C_ADDRESS, BMP280_DEVICE_ID))
    {
        SerialUSB.println(F("Could not find a valid BMP280 sensor, check wiring!"));
        while (1)
            ;
    }
    SerialUSB.println("BMP280 found");

    /* Default settings from datasheet. */
    bmp.setSampling(Adafruit_BMP280::MODE_NORMAL,     /* Operating Mode. */
                    Adafruit_BMP280::SAMPLING_X2,     /* Temp. oversampling */
                    Adafruit_BMP280::SAMPLING_X16,    /* Pressure oversampling */
                    Adafruit_BMP280::FILTER_X16,      /* Filtering. */
                    Adafruit_BMP280::STANDBY_MS_500); /* Standby time. */

    SerialUSB.println("BMP280 init over");

    dht.begin();
    SerialUSB.println("DHT11 init over");
}

void sensor_read(Sensor_value *s_v)
{
    s_v->humidity = dht_humi();
    s_v->temperature = dht_temp();
    s_v->pressure_value = bmp_pa();
    s_v->direct = wind_dir();
    //s_v->pm25 = pm25();
}

int bmp_pa()
{
    return bmp.readPressure();
}

int dht_temp()
{
    float t = dht.readTemperature();
    return (int)(t * 10.0);
}

int dht_humi()
{
    float h = dht.readHumidity();
    return (int)h;
}

int wind_dir()
{
    int adc_value = analogRead(A1);
    SerialUSB.print("Direct:");
    SerialUSB.println(adc_value);
    return (adc_value + 70) / 140;
}

float pm25()
{
    int samplingTime = 280;
    int deltaTime = 40;
    int sleepTime = 9680;

    float voMeasured = 0;
    float calcVoltage = 0;
    float dustDensity = 0;
    digitalWrite(PM_LED_PIN, HIGH); // power on the LED
    delayMicroseconds(samplingTime);

    voMeasured = analogRead(PM_READ_PIN); // read the dust value
    SerialUSB.print("PM AD0=");
    SerialUSB.println(voMeasured);       //
    voMeasured = voMeasured * 2.0 / 3.0; //5V to 3.3V   average is a better way
    delayMicroseconds(deltaTime);
    digitalWrite(PM_LED_PIN, LOW); // turn the LED off
    delayMicroseconds(sleepTime);

    // if (voMeasured < 10)
    //     return 0;
    // 0 - 5V mapped to 0 - 1023 integer values
    // recover voltage
    calcVoltage = voMeasured * (5.0 / 1024.0);

    // linear eqaution taken from http://www.howmuchsnow.com/arduino/airquality/
    // Chris Nafis (c) 2012
    dustDensity = 170 * calcVoltage - 0.1;

    SerialUSB.print(dustDensity); // unit: ug/m3
    SerialUSB.println("ug/m3");
    return dustDensity;
}

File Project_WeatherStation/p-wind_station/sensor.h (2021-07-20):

#include <DHT.h>
#include <Adafruit_BMP280.h>

#define BMP280_I2C_ADDRESS 0x76
#define BMP280_DEVICE_ID 0x58

#define DHTPIN 13 // the number of the DHT11 pin
#define DHTTYPE DHT11

#define DIRECT_PIN A1

#define PM_READ_PIN A1
#define PM_LED_PIN 10

typedef struct
{
    int humidity;
    int temperature;
    int speed;
    int direct;
    int pressure_value;
    float pm25;
} Sensor_value;

void sensor_init();
void sensor_read(Sensor_value *s_v);
void dht_init();
int dht_temp();
int dht_humi();

int bmp_pa();
int wind_dir();
float pm25();

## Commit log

2021-03-13 Add low power example
2021-04-28 add hardware
    [Wind Weather Station V2.1.brd, Wind Weather Station V2.1.sch]
2021-05-05 Add Seeed UV sensor support
2021-07-20 Add weather project
    [weahter.csv, weathersation_1.stl, weathersation_2.stl.stl]

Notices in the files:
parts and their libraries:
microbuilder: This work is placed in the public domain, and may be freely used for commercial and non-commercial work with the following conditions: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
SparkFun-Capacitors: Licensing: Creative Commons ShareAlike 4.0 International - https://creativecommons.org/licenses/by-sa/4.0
